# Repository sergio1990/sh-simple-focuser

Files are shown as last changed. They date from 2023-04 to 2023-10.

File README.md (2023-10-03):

# SHSimpleFocuser

Quite a simple yet workable ASCOM-compatible handmade automatic focuser.

### Technical characteristics

The driving part of the focuser is a 28BYJ-48 stepper motor which needs 5V of
power and it draws only about 240 mA of the current. Such characteristics of
the motor give an ability to use the USB connection to power the motor.
[Here](https://lastminuteengineers.com/28byj48-stepper-motor-arduino-tutorial/)
is a good overview of that stepper motor.

According to that article in full step mode the motor does `2038` steps per
revolution. Bearing in mind that the gear ratio is `1:4` the total number of
steps in order to the focuser's output shaft to make the full revolution is
`2038 * 4 => 8152`.

The article also mentions the torque of the stepper motor - `34.3 mN*m` which
roughly corresponds to the `350 g*force*cm`. Again, using the gear ratio of
`1:4` the torque of the output shaft is about `1.4 kg*force*cm`. Which is quite
okay, but ideally it's better to have a better margin between the minimum
required value and the maximum torque the focuser can supply. I weighted all
the imaging train I put into the focuser and it weights about `700-800 g`, so
having about `1.4 kg*force*cm` torque from the focuser (and some torque we lose
due to friction, etc.) might be not enough - actually, when tightening focuser
screws up I noticed the focuser almost stopped moving and just skipped steps 😬
Therefore, it's better to have a bigger margin - I believe, something 2x and
higher should be a sweet spot.

I think I'll rebuild the focuser entirely reusing some of the 12V stepper
motors, which initially might provide the `1.4 kg*force*cm` torque and adding
some gear system we can drastically increase it. The downside of this we'll
need additional wiring to provide a 12V power supply, but anyway we already get
it right to the camera, so it's not an issue.

### Breadboard Schematic

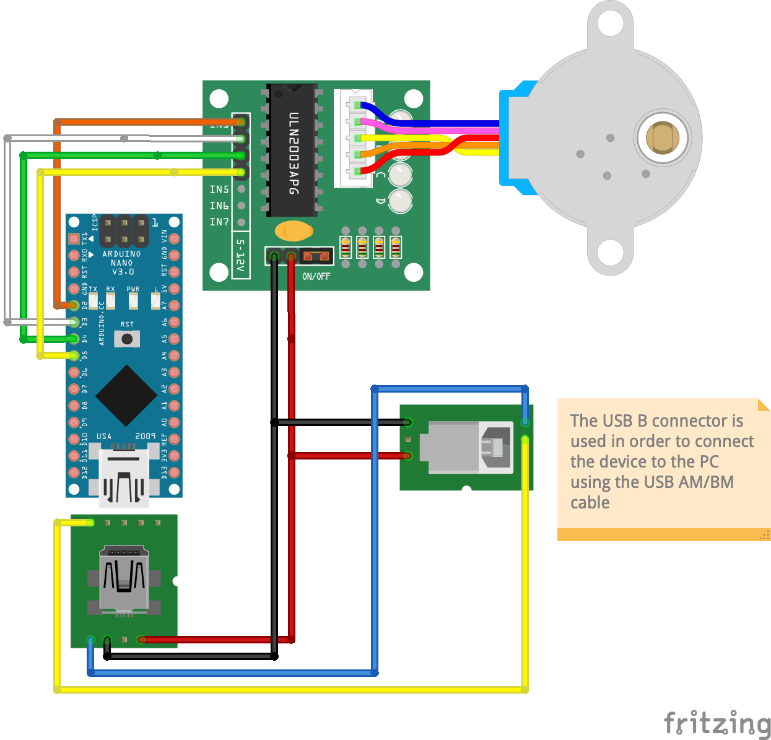
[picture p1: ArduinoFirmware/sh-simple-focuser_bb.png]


### 3D Design

Under the 3DDesign folder there is a [Fusion 360 design
file](./3DDesign/simple-focuser.f3z). Basically, during the design
phase the focuser looked like the following:

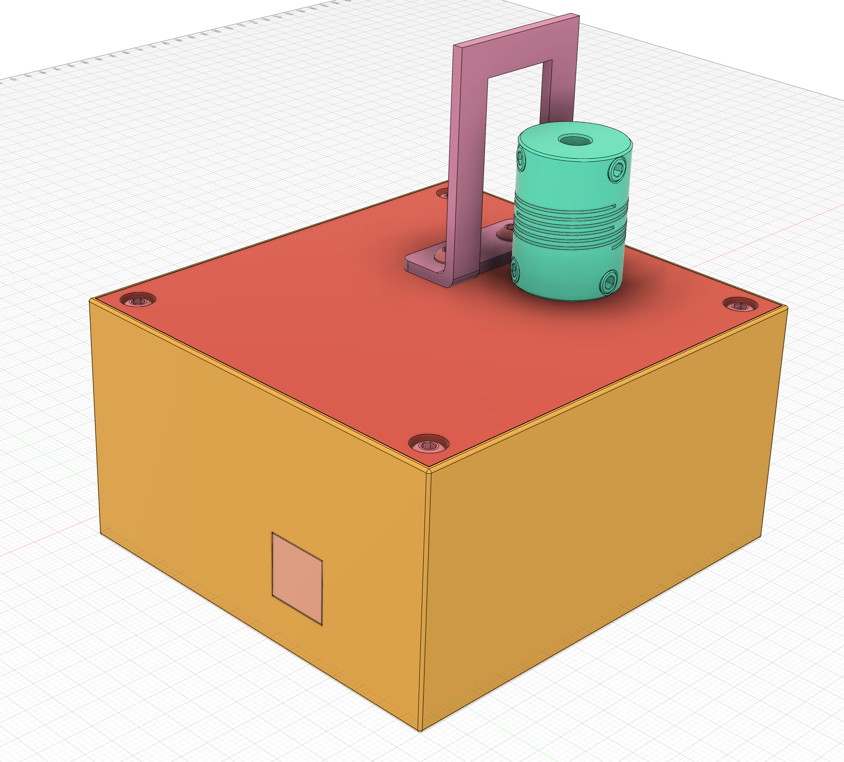
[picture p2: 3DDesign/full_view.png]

<br/>
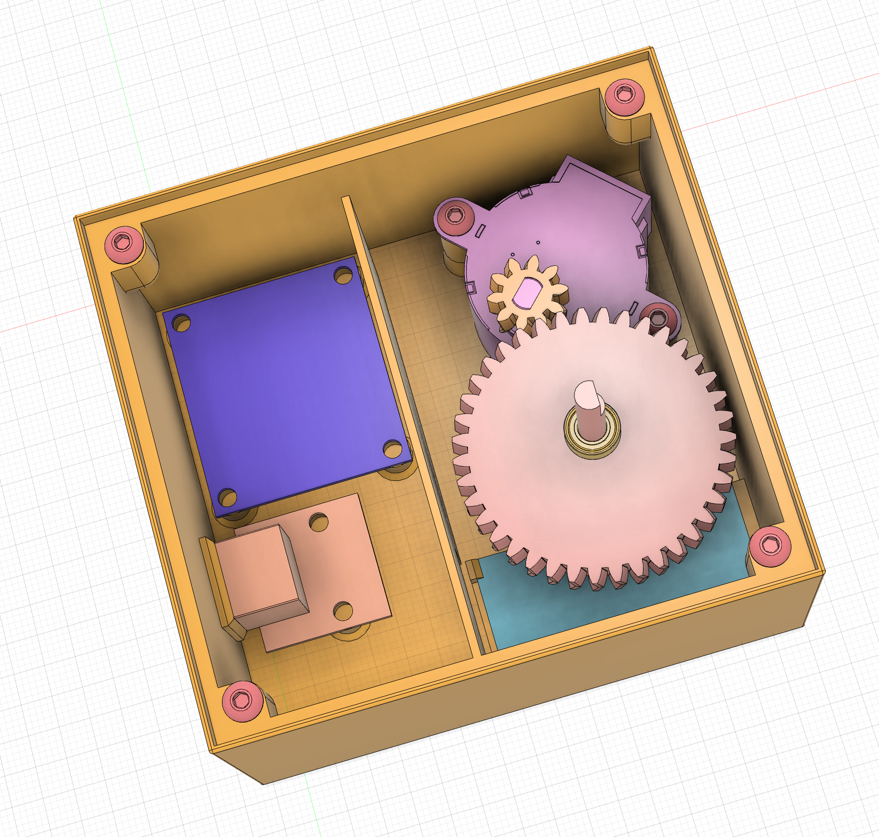
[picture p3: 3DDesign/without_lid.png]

<br/>
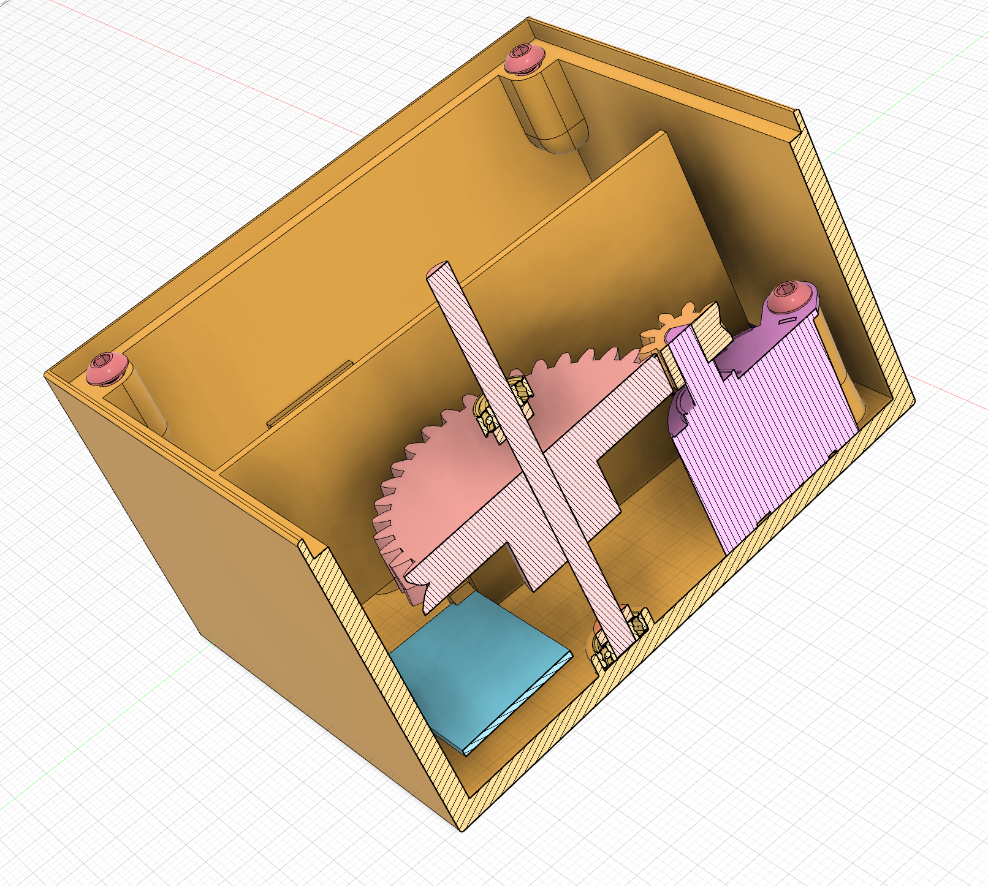
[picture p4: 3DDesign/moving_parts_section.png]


### N.I.N.A: Autofocus setup

The N.I.N.A. astrophotography software provides the autofocusing feature and
now having the automated focuser it makes sense to setup the autofocus. There
is a great [video](https://www.youtube.com/watch?v=lHrfaR7A0L0) about how to
setup auto-focus in N.I.N.A. quickly and correctly. I tried to follow mentioned
steps and that's how the autofocus setup looks in my case:

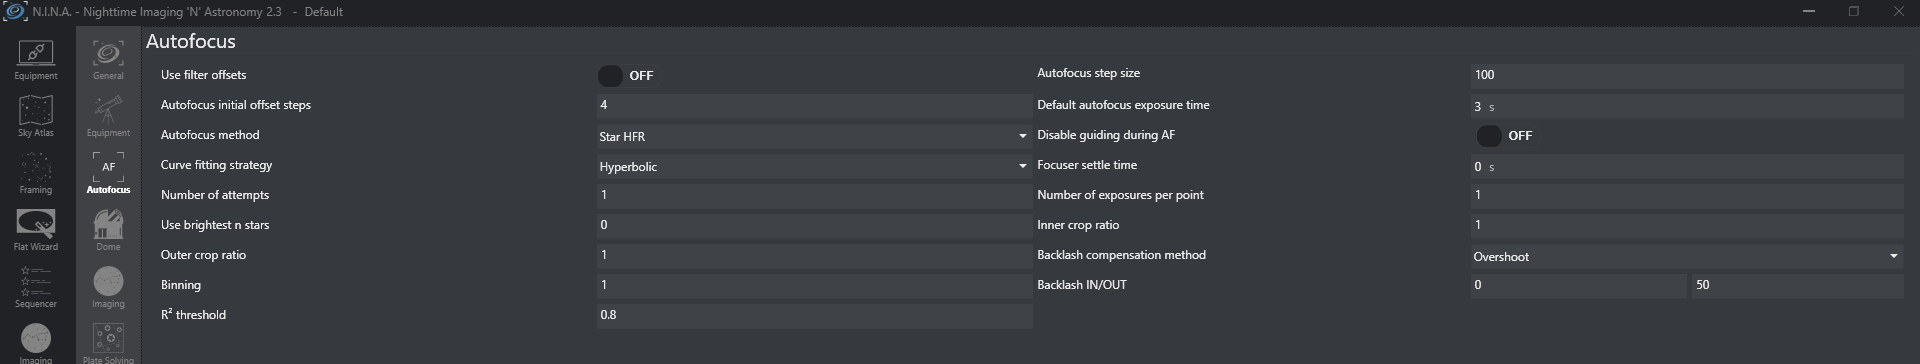
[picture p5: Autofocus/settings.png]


Once applied all the settings the autofocus routine went correctly and the
graph looks quite great:

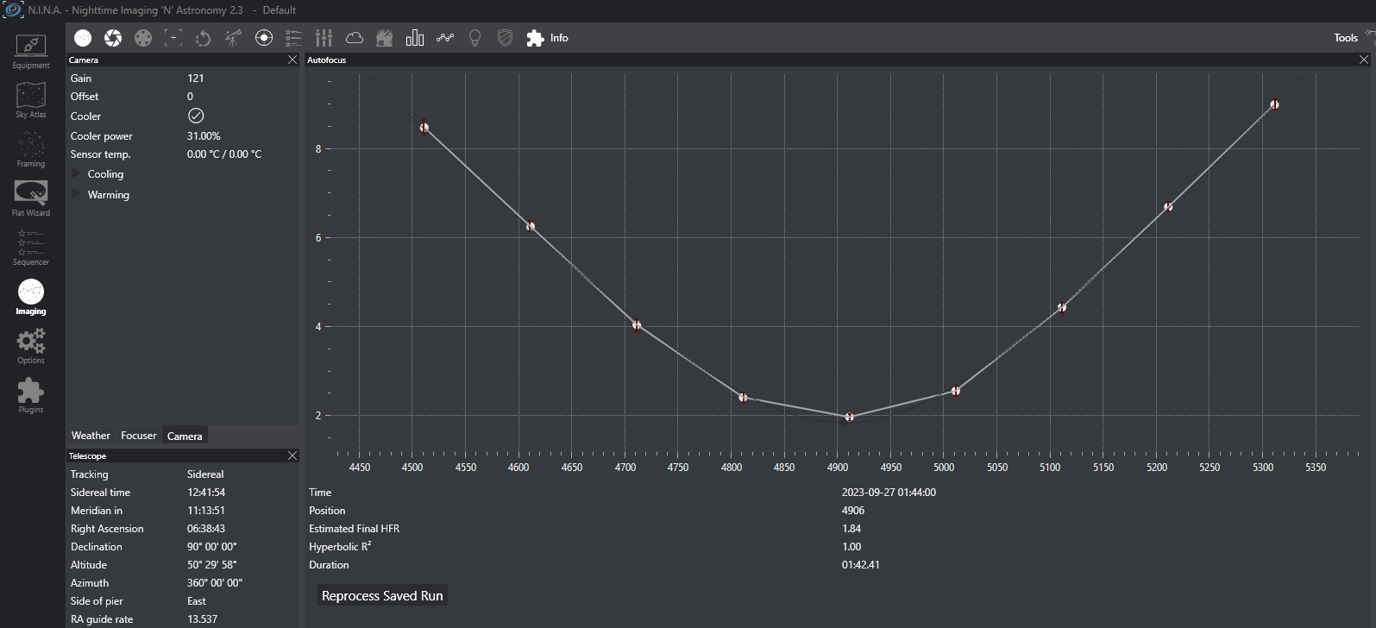
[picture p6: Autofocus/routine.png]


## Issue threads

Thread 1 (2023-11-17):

Adapting driver to RA and DEC axis guiding through PHD2

Pedroscope, 2023-11-17:
Is it possible to use this driver to control RA and DEC axis using 2828BYJ-48 motor with a ULN2003 controller?

sergio1990, 2024-03-05:
Excuse me, I just saw this opened issue and for sure it might be irrelevant at the moment, but want to close the loop anyway. There are several points that make this driver as well as the hardware not suitable for the RA and DEC axis guiding:

1. The 2828BYJ-48 motor has too low torque to move the mount with the telescope. Even for the focuser device, I believe it works for me almost at the maximum of its capabilities. It's better to use NEMA17 motors with, for instance, TMC drivers.
2. I'm afraid it's not possible to use this driver as-is - it's specifically written for controlling the focuser device. For controlling RA/DEC axis we need to implement another ASCOM interface - `ITelescopeV3` - which provides a specific set of methods for telescope control. One day I've found [this](https://github.com/kevinferrare/arduino-st4) repo which can be used as an example.

Closed 2024-03-05.

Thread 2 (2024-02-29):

Error while installing the ASCOM Driver

jugal2001, 2024-02-29:
I ran the script using inno and got the below error.

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
I'd appreciate any help with this, thanks.

sergio1990, 2024-03-05:
In DM we've figured out that the driver's DLL has to be built first before compiling the installer. The repo doesn't include any pre-built resources.

Closed 2024-03-05.

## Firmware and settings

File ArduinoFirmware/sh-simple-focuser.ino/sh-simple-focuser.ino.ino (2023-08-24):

#include <AccelStepper.h>

constexpr auto DEVICE_GUID = "906335CB-A62C-4134-B41E-7C2A4CF44D0C";

// Creates an instance
// Pins entered in sequence IN1-IN3-IN2-IN4 for proper step sequence
AccelStepper myStepper(AccelStepper::FULL4WIRE, 2, 4, 3, 5);

bool isConnected = false;

void setup() {
  Serial.begin(57600, SERIAL_8N1);
  Serial.setTimeout(100);
  while (!Serial);
  Serial.println("INITIALIZED#");

  myStepper.setCurrentPosition(0);
	myStepper.setMaxSpeed(200.0);
  myStepper.disableOutputs();
}

void loop() {
  if (Serial.available() > 0) {
    String command = Serial.readStringUntil('#');
    String response = processCommand(command);
    Serial.println(response);
  }

  myStepper.runSpeedToPosition();
}

String processCommand(String command) {
  char commandCode = command[0];

  String stepsString = command.substring(1);
  int stepsNumber = stepsString.toInt();
  bool isRunning = myStepper.isRunning() && myStepper.distanceToGo() != 0;

  switch(commandCode) {
    // CONNNECT
    case 'C':
      myStepper.enableOutputs();
      isConnected = true;
      return "OK#";
    // DISCONNECT
    case 'D':
      if(isRunning) {
        myStepper.setSpeed(0);
        myStepper.move(0);
        myStepper.runToPosition();
      }
      isConnected = false;
      myStepper.disableOutputs();
      return "OK#";
    // FORWARD steps
    case 'F':
      if(!isConnected) { return "NOK#"; }
      myStepper.move(-stepsNumber);
      myStepper.setSpeed(200);
      return "OK#";
    // BACKWARD steps
    case 'B':
      if(!isConnected) { return "NOK#"; }
      myStepper.move(stepsNumber);
      myStepper.setSpeed(200);
      return "OK#";
    // STOP
    case 'S':
      if(!isConnected) { return "NOK#"; }
      myStepper.setSpeed(0);
      myStepper.move(0);
      myStepper.runToPosition();
      return "OK#";
    // PING
    case 'P':
      return "OK:" + String(DEVICE_GUID) + "#";
    // STATUS (aka WHAT)
    case 'W':
      if(!isConnected) { return "NOK#"; }
      return isRunning ? "MOVING#" : "IDLE#";
    default:
      return "UNKNOWN#";
  }
}

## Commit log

2023-03-13 Add generated ASCOM driver code
2023-03-14 Add initial driver implementation
2023-03-14 Add fixes to make it alive
    [sh-simple-focuser.ino.ino]
2023-03-14 Add driver installer
2023-04-06 Add Fritzing files
    as well as preview image
    [sh-simple-focuser.fzz]
2023-08-07 Improve usage of the AccelStepper lib
    - runSpeed -> runSpeedToPosition
    - no need to call the stop method
    - no need to set the negative speed when going backward
    - switch to use the full step
    - for stopping the motor set the speed to 0
2023-08-17 Fix status when going focus in
    Also switch to the half steps
    [sh-simple-focuser.ino.ino]
2023-08-24 Add adjustments after adding the gear system
